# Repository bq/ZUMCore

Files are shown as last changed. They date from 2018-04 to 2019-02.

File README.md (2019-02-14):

# ZUMCore 2
BQ ZUM Core integration on Arduino IDE

This is the evolution of the bqZUM Core board available [here](https://github.com/bq/zum).
Main changes are:
1. Move to Bluetooth Low Energy (BLE).
1. Change from ATMega328P to ATMega328PB.

## Getting Started

### Prerequisites

You need to install latest [Arduino IDE](https://www.arduino.cc/en/Main/Software).

This package has been tested on Arduino IDE 1.8.5.

### Installing

To use the integration with Arduino IDE follow these steps:
1. Open Arduino IDE and go into File -> Preferences.
1. On "Additional Boards Manager URLs:" enter the link to [package_zumcore_1_8_x_index.json](https://raw.githubusercontent.com/bq/ZUMCore/master/package_zumcore_1_8_x_index.json) [right click here and copy link] and press OK.
1. Go to Tools -> Boards -> Board Manager and you will find "ZUM Core for Arduino 1.8.x" ready to be installed. Install latest version.

Now you can choose your Board **BQ ZUM Core**.

You can also find some usefull examples for the board available on the IDE.

### Examples

## Flashing Bootloader

The bootloader can be flashed on ZUM Core using another Arduino board as ISP or any other supported ISP programmer.
For further support check this [link](https://www.arduino.cc/en/Tutorial/ArduinoISP).

## License

This project is licensed under the GPL v3 license.

## Credits

This project relies on Arduino IDE to work.

The project is based on [Elektor UNO R4](https://github.com/ElektorLabs/Arduino/)

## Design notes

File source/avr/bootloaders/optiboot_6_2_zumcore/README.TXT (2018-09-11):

------------------------------------------------------------
bqZUM Core

This is a slightly modified version to make optiboot compile for 
the ATmega16 too. 

The make rules for the Elektor boards are in Makefile.custom.
The easiest way to make this work is to copy this folder and its 
contents to:

  <Arduino>\hardware\arduino\avr\bootloaders\

where <Arduino> is the path to arduino.exe.

Open a command prompt and navigate to the newly added folder, ex:

  <Arduino>\hardware\arduino\avr\bootloaders\optiboot_6_2_zumjunior\

Enter this folder and then try make commands, like this:

  make atmega328pb LED=B5

This should result in a usable HEX file.
------------------------------------------------------------

This directory contains the Optiboot small bootloader for AVR
microcontrollers, somewhat modified specifically for the Arduino
environment.

Optiboot is more fully described here: http://github.com/Optiboot/optiboot
and is the work of Peter Knight (aka Cathedrow), building on work of Jason P
Kyle, Spiff, and Ladyada.  More recent maintenance and modifications are by
Bill Westfield (aka WestfW)

Arduino-specific issues are tracked as part of the Arduino project
at http://github.com/arduino/Arduino

Most of the information in this file is superceeded by the wiki content at
https://github.com/Optiboot/optiboot/wiki

It's till here "just in case."

------------------------------------------------------------

Building optiboot for Arduino.

Production builds of optiboot for Arduino are done on a Mac in "unix mode"
using CrossPack-AVR-20100115.  CrossPack tracks WINAVR (for windows), which
is just a package of avr-gcc and related utilities, so similar builds should
work on Windows or Linux systems.

One of the Arduino-specific changes is modifications to the makefile to
allow building optiboot using only the tools installed as part of the
Arduino environment, or the Arduino source development tree.  All three
build procedures should yield identical binaries (.hex files) (although
this may change if compiler versions drift apart between CrossPack and
the Arduino IDE.)

Building Optiboot in the Arduino IDE Install.

Work in the .../hardware/arduino/bootloaders/optiboot/ and use the
"omake <targets>" command, which just generates a command that uses
the arduino-included "make" utility with a command like:
    make OS=windows ENV=arduino <targets>
or  make OS=macosx ENV=arduino <targets>
On windows, this assumes you're using the windows command shell.  If
you're using a cygwin or mingw shell, or have one of those in your
path, the build will probably break due to slash vs backslash issues.
On a Mac, if you have the developer tools installed, you can use the
Apple-supplied version of make.
The makefile uses relative paths ("../../../tools/" and such) to find
the programs it needs, so you need to work in the existing optiboot
directory (or something created at the same "level") for it to work.

Building Optiboot in the Arduino Source Development Install.

In this case, there is no special shell script, and you're assumed to
have "make" installed somewhere in your path.
Build the Arduino source ("ant build") to unpack the tools into the
expected directory.
Work in Arduino/hardware/arduino/bootloaders/optiboot and use
    make OS=windows ENV=arduinodev <targets>
or  make OS=macosx ENV=arduinodev <targets>

Programming Chips Using the _isp Targets

The CPU targets have corresponding ISP targets that will actuall
program the bootloader into a chip. "atmega328_isp" for the atmega328,
for example.  These will set the fuses and lock bits as appropriate as
well as uploading the bootloader code.

ISP Targets in Version 5.0 and later:

The isp targets are now built using a separate "Makefile.isp" makefile,
which should make modification easier and more obvious.  This also fixes
the atmega8_isp target problem mentioned below.  The default
configuration assumes an ArduinoISP setup, but you will probably need to
update at least the serial port, since those are different for each
Arduino board and/or system/

ISP Targets in Version 4.6 and earlier:

The older makefiles default to using a USB programmer, but you can use a
serial programmer like ArduinoISP by changing the appropriate variables
when you invoke make:

   make ISPTOOL=stk500v1 ISPPORT=/dev/tty.usbserial-A20e1eAN  \
        ISPSPEED=-b19200 atmega328_isp

The "atmega8_isp" target does not currently work, because the mega8
doesn't have the "extended" fuse that the generic ISP target wants to
pass on to avrdude.  You'll need to run avrdude manually.

Standard Targets

I've reduced the pre-built and source-version-controlled targets
(.hex and .lst files included in the git repository) to just the
three basic 16MHz targets: atmega8, atmega16, atmega328.

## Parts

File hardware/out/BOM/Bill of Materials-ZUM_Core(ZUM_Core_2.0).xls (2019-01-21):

 |  |  | BILL OF MATERIALS
PROJECT: |  | ZUM_Core.PrjPcb
TITLE: |  | ZUM Core
VARIANT: |  | ZUM_Core_2.0
DOCUMENT: |  | Bill of Materials
AUTHOR : |  | Andrés Gullón
DATE : |  | 01/06/2018
REV: |  | 1.I.
NOTE | ITEM | Designator | Description | Quantity | Manufacturer | OrderingCode | Supplier | Manufacturer 2 | OrderingCode 2 | Manufacturer 3 | OrderingCode 3 | Manufacturer 4 | OrderingCode 4 | Manufacturer 5 | OrderingCode 5 | Footprint | Value
 | 1 | C1, C2, C7, C8, C10, C17, C20, C21, C22, C26 | C0603_100nF_50V_±10%_X7R | 10 | Kemet | C0603C104K5RAC | - | AVX | 06035C104KAT2A |  |  |  |  |  |  | C0603 | 100nF ±10% 50V
 | 2 | C3, C4, C5, C6, C9, C14 | C0402_2.2uF_16V_±20%_X5R | 6 | TDK | C1005X5R1C225M050BC | - | Taiyo Yuden | EMK105ABJ225MV-F |  |  |  |  |  |  | C0402 | 2,2µF ±20% 16V
 | 3 | C11, C12 | C0402_47pF_16V_±10% | 2 | Kemet | C0402C470K4GAC | - |  |  |  |  |  |  |  |  | C0402 | 47pF ±10% 16V
 | 4 | C13 | C0805_4700pF_250V_±10%_X7R | 1 | Kemet | C0805S472KARACTU | - | Murata | GRM21AR72E472KW01D |  |  |  |  |  |  | C0805 | 4,7nF ±10% 250V
 | 5 | C15 |  | 1 | Kemet | C0603C105K3PAC | - |  |  |  |  |  |  |  |  | C0603 | 1uF ±10% 25V
 | 6 | C16, C27, C28 |  | 3 | Murata | GRM31CR61E226KE15L | - |  |  |  |  |  |  |  |  | C1206 | 22uF ±10% 25V
 | 7 | C18, C23 | C0402_2.2nF_16V_±10% | 2 | Kemet | C0402C222K4RAC | - |  |  |  |  |  |  |  |  | C0402 | 2,2nF ±10% 16V
 | 8 | C19, C32 | C0402_47nF_16V_±10%, [NoValue] | 2 | Kemet | C0402C473K4RAC | - |  |  |  |  |  |  |  |  | C0402 | 47nF ±10% 16V
 | 9 | C24, C25 | C0402_12pF_16V_±10% | 2 | Kemet | C0402C120K4GAC | - |  |  |  |  |  |  |  |  | C0402 | 12pF ±10% 16V
 | 10 | C30 |  | 1 | Vishay | T55B157M6R3C0040 | - |  |  |  |  |  |  |  |  | CASE_B_3528-1411 | 150uF ±20% 6V3
 | 11 | C31 |  | 1 | Panasonic | EEE-HA1E101XP | - |  |  |  |  |  |  |  |  | CASE_D_7.7 | 100uF 25V
 | 12 | C33 |  | 1 | Kemet | C0402C104K9RAC | - |  |  |  |  |  |  |  |  | C0402 | 100nF ±10% 6V3
 | 13 | D1 | Schottky Diode | 1 | NXP | BAT54S | - | Vishay | BAT54S |  |  |  |  |  |  | SOT23-3 | 200mA 30V
 | 14 | D2, D6 | Schottky Diode | 2 | NXP | PMEG3030EP | - |  |  |  |  |  |  |  |  | SOD128 | 3A 30V
 | 15 | D3, D4, TX | LED | 3 | Avago Technologies | HSMG-C190 | - | OSRAM Opto | LG Q971-KN-1 |  |  |  |  |  |  | LED0603 | Green
 | 16 | F1 | Resettable Fuses | 1 | Bel Fuse | 0ZCG0260BF2B | - | Littelfuse | MINISMDC260F/16-2 | Bourns | MF-MSMF250/16X-2 |  |  |  |  | F1812
 | 17 | F2 | TVS Diode Array | 1 | Würth Elektronik | 82400152 | - | Bourns | CDSOT563-0502 |  |  |  |  |  |  | SOT563
 | 18 | F3 | Resettable Fuses | 1 | Bourns | MF-MSMF050-2 | - |  |  |  |  |  |  |  |  | F1812
 | 19 | F4 | 2.45GHz Impedance Matched Balun + Band Pass Filter | 1 | Johanson | 2450BM14E0003 | - |  |  |  |  |  |  |  |  | BAL-0603-6PIN | Balun 2.45GHz
 | 20 | J1 | Micro USB Type B W/ Rear Pegs | 1 | FCI | 10118194-0001LF | - |  |  |  |  |  |  |  |  | USB_B_W_REAR_PEGS
 | 21 | J2 | Connector | 1 | Samtec | TSW-108-07-T-S-NATURAL | - |  |  |  |  |  |  |  |  | 1x8 Pin Header 2.54
 | 22 | J3 | Connector | 1 | Samtec | TSW-108-07-T-S-RED | - |  |  |  |  |  |  |  |  | 1x8 Pin Header 2.54
 | 23 | J4 | Connector | 1 | Samtec | TSW-108-07-T-S | - | Würth Elektronik | 613 008 111 21 |  |  |  |  |  |  | 1x8 Pin Header 2.54 | 8
 | 24 | J5, J11 | Connector | 2 | Samtec | SSW-108-01-T-S | - | Würth Elektronik | 613 008 118 21 |  |  |  |  |  |  | 1x8 Socket Header THT 2.54mm | 8
 | 25 | J6 | Connector | 1 | Samtec | TSW-106-07-T-S-NATURAL | - |  |  |  |  |  |  |  |  | 1x8 Header 2.54 (3D Mod)
 | 26 | J7, J13 | Connector | 2 | Samtec | TSW-106-07-T-S-RED | - |  |  |  |  |  |  |  |  | 1x8 Header 2.54 (3D Mod), 1x6 Pin Header 2.54
 | 27 | J8, J14 | Connector | 2 | Samtec | TSW-106-07-T-S | - | Würth Elektronik | 613 006 111 21 |  |  |  |  |  |  | 1x8 Header 2.54 (3D Mod), 1x6 Pin Header 2.54 | 6
 | 28 | J9 | Connector | 1 | Samtec | SSW-106-01-T-S | - | Würth Elektronik | 613 006 118 21 |  |  |  |  |  |  | 1x6 Socket Header THT 2.54mm | 6
 | 29 | J10 | Connector | 1 | Samtec | TSW-103-07-T-D | - | Würth Elektronik | 613 006 211 21 |  |  |  |  |  |  | 2x3 Pin Header 2.54 | 6
 | 30 | J12 | Connector | 1 | Samtec | TSW-106-07-T-S-BLUE | - |  |  |  |  |  |  |  |  | 1x6 Pin Header 2.54
 | 31 | J15 | Connector | 1 | Samtec | SSW-110-01-T-S | - | Würth Elektronik | 613 010 118 21 |  |  |  |  |  |  | 1x10 Socket Header THT 2.54mm | 10
 | 32 | J_PWR | Connector | 1 | Kycon | KLDHCX0202A | - | Switchcraft | RAPC722X |  |  |  |  |  |  | Jack 2.1
 | 33 | L1 | L0603_120R_0,025R_3000mA | 1 | Murata | BLM18SG121TN1D | - |  |  |  |  |  |  |  |  | L0603 | 120R 0,025R 3000mA
 | 34 | L2 |  | 1 | Würth Elektronik | 742792012 | - |  |  |  |  |  |  |  |  | L0805 | 33R 0,008R 4000mA
 | 35 | L3 | Semi-shielded power inductor | 1 | Bourns | SRN8040-2R2Y | - |  |  |  |  |  |  |  |  | SRN8040 | 2,2µH 6,3A
 | 36 | LD4 | LED | 1 | Lite-On | LTST-C194TBKT | - | Avago Technologies | HSMN-C120 |  |  |  |  |  |  | LED0603 | Blue
 | 37 | Q1, Q2, Q3, Q4 | P-MOSFET transistor | 4 | Diodes Incorporated | DMP2035U-7 | - |  |  |  |  |  |  |  |  | SOT23-3
 | 38 | R1, R7 | R0603_1M_0.1W_±5% | 2 | Vishay | CRCW06031M00JN | - |  |  |  |  |  |  |  |  | R0603 | 1M ±5% 0.1W
 | 39 | R2, R4, R5, R15 | R0402_1k_0.063W_±5% | 4 | Vishay | CRCW04021K00JN | - |  |  |  |  |  |  |  |  | R0402 | 1k ±5% 0.063W
 | 40 | R3 | R0402_10R_0.063W_±1% | 1 | Vishay | CRCW040210R0FK | - | Yageo | RC0402FR-0710RL |  |  |  |  |  |  | R0402 | '=Resistance+' '+Tolerance+' '+Power
 | 41 | R6, R11, R19 | R0402_100k_0.063W_±1%, [NoValue], [NoValue] | 3 | Vishay | CRCW0402100KFK | - |  |  |  |  |  |  |  |  | R0402 | 100k ±1% 0.063W
 | 42 | R8, R18, R20, R23 | R0402_330R_0.063W_±5% | 4 | Vishay | CRCW0402330RJN | - |  |  |  |  |  |  |  |  | R0402 | 330R ±5% 0.063W
 | 43 | R9, R14, R22 |  | 3 | Vishay | CRCW040252K3FK | - |  |  |  |  |  |  |  |  | R0402 | 52,3k ±1% 0.063W
 | 44 | R10, R17, R25 | R0402_10k_0.063W_±5% | 3 | Vishay | CRCW040210K0JN | - | Yageo | RC0402JR-0710KL |  |  |  |  |  |  | R0402 | 10k ±5% 0.063W
 | 45 | R12 | R0402_20R_0.063W_±5% | 1 | Vishay | CRCW040220R0JN | - |  |  |  |  |  |  |  |  | R0402 | 20R ±5% 0.063W
 | 46 | R13 | R0402_75k_0.063W_±1% | 1 | Vishay | CRCW040275K0FK | - | Yageo | RC0402FR-0775KL |  |  |  |  |  |  | R0402 | 75k ±1% 0.063W
 | 47 | R16 | R0402_82k_0.063W_±1% | 1 | Vishay | CRCW040282K0FK | - | Yageo | RC0402FR-0782KL |  |  |  |  |  |  | R0402 | 82k ±1% 0.063W
 | 48 | R24 | R0402_30k_0.063W_±1% | 1 | Vishay | CRCW040230K0FK | - |  |  |  |  |  |  |  |  | R0402 | 30k ±1% 0.063W
 | 49 | RX | LED | 1 | Avago Technologies | HSMH-C190 | - | OSRAM Opto | LS Q976-NR-1 |  |  |  |  |  |  | LED0603 | Red
 | 50 | SW1 | Switch | 1 | C&K Components | PTS645VL39-2 LFS | - |  |  |  |  |  |  |  |  | SW_Vert_THT_7.5x6x6.5
 | 51 | SW2 | Switch | 1 | Würth Elektronik | 450 302 014 072 | - | Knitter-Switch | MMP1010D-RA |  |  |  |  |  |  | Slide SW SPDT Right Angle
 | 52 | U1 | 8-bit Microcontrollers - MCU 32KB In-system Flash 20MHz 1.8V-5.5V | 1 | Atmel | ATMEGA328PB-AU | - |  |  |  |  |  |  |  |  | TQFP32
 | 53 | U2 | USB to UART Bridge | 1 | Silicon Labs | CP2104-F03-GMR | - |  |  |  |  |  |  |  |  | QFN24_no_power
 | 54 | U3 | DCDC Step Down Vout= 1-5V; Vin= 12-17V | 1 | MPS | MP1477GTF-Z | - |  |  |  |  |  |  |  |  | SOT-563 - MP1477H
 | 55 | U4 | Multiplexer | 1 | Texas Instruments | SN74CBT3257CPWR | - |  |  |  |  |  |  |  |  | TSSOP16
 | 56 | U5 | Multiprotocol Bluetooth® low energy/2.4 GHz RF System on Chip | 1 | Nordic | NRF51822-QFAB-T | - |  |  |  |  |  |  |  |  | QFN_48_6x6mm | BLE
 | 57 | U6 | LDO Vin: 3-40V Vout: 1.2-15V @300mA | 1 | Monolithic Power Systems | MP2019GN-Z | - |  |  |  |  |  |  |  |  | SOIC8 EP
 | 58 | Y1 | Resonator 16MHz | 1 | Murata | CSTCE16M0V53-R0 | - |  |  |  |  |  |  |  |  | Resonator_1.3x3.2 | 16MHz
 | 59 | Y2 | Crystal 16 MHz | 1 | Abracon | ABM8G-16.000MHZ-B4Y-T | - | TXC | 7V-16.000MAHQ-T | CTS | 403C35A16M00000 |  |  |  |  | ABM8G_3.2x2.5mm | 16MHz
 | 60 | Zs | R0402_0R_0.063W_±5% | 1 | Panasonic | ERJ-2GE0R00X | - | Yageo | RC0402FR-070RL | Vishay | CRCW04020000Z0 |  |  |  |  | R0402 | 0R ±5% 0.063W
NOTES:

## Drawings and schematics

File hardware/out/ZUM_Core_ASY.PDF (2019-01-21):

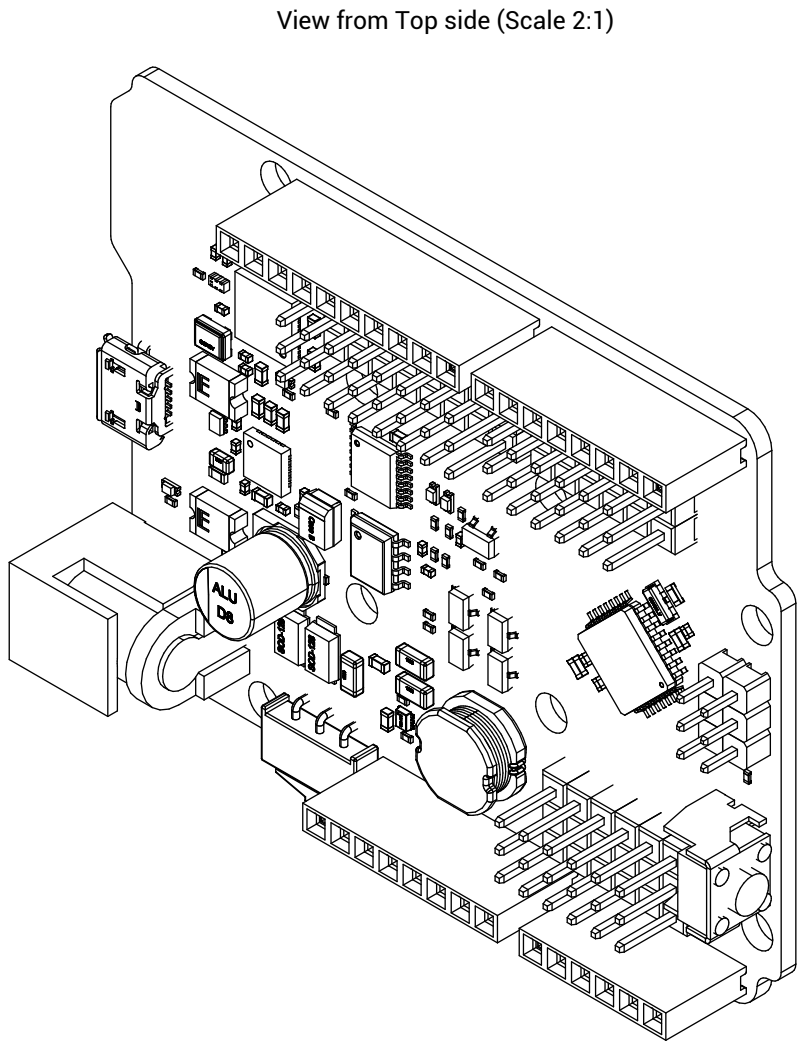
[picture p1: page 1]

View from Top side (Scale 2:1)

ZUM_Core_2.0 | SCALE | 2:1

REVISION | =1.I.1
UNIT | UNLESS OTHERWISE SPECIFIED: DIMENSIONS ARE IN MILLIMETERS

PROJECTION

A3 | SHEET 1 OF 2

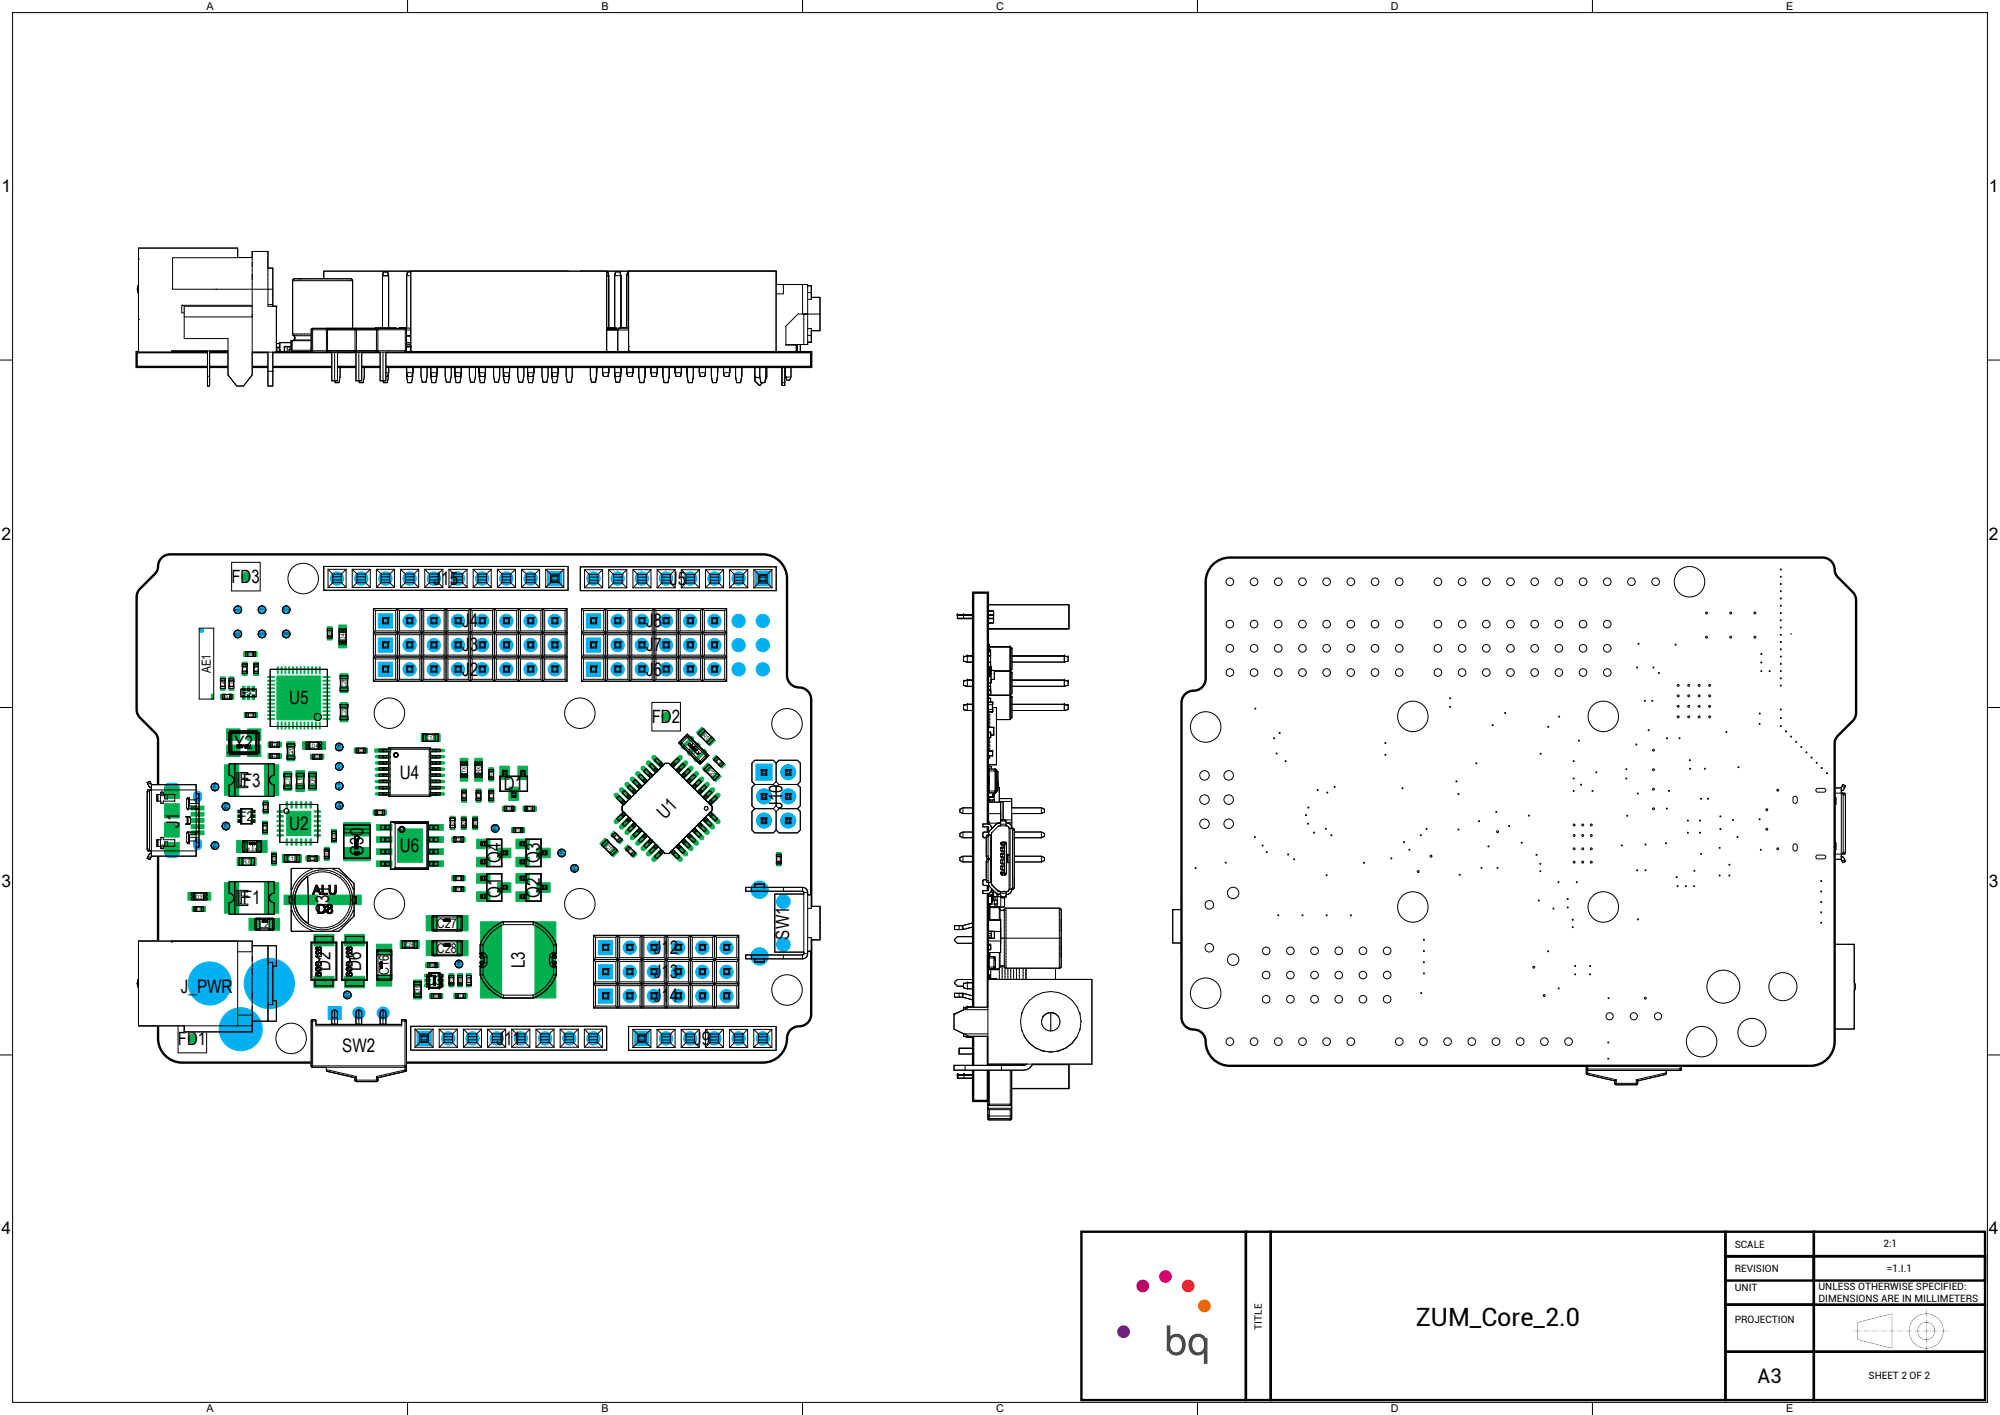
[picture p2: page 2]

ZUM_Core_2.0 | SCALE | 2:1

REVISION | =1.I.1
UNIT | UNLESS OTHERWISE SPECIFIED: DIMENSIONS ARE IN MILLIMETERS

PROJECTION

A3 | SHEET 2 OF 2

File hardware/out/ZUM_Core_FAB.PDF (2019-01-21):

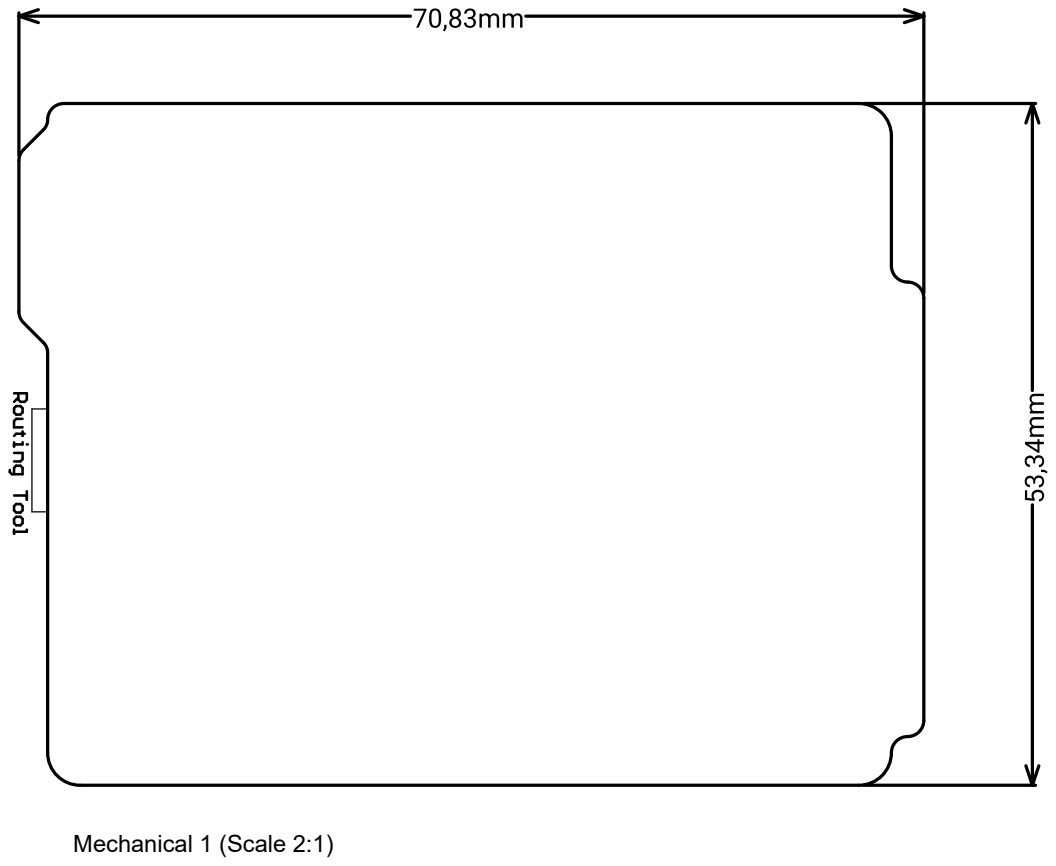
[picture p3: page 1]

SURFACE FINISH: | | SOLDERMASK COLOR: TITLE ZUM_Core_2.0 | SCALE | 2:1

HAL / Inmersion TIN / Inmersion Silver | White | SILKSCREEN COLOR: Black

REVISION | =1.I.1
UNIT | UNLESS OTHERWISE SPECIFIED: DIMENSIONS ARE IN MILLIMETERS

PROJECTION

A3 | SHEET 1 OF 3

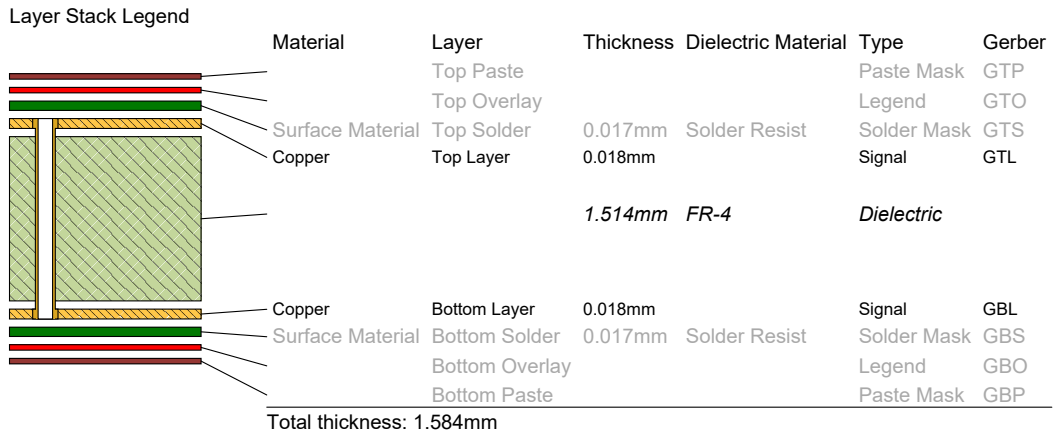
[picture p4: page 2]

SURFACE FINISH: | | SOLDERMASK COLOR: TITLE | SCALE | 2:1

HAL / Inmersion TIN / Inmersion Silver | White | SILKSCREEN COLOR: Black

REVISION | =1.I.1
UNIT | UNLESS OTHERWISE SPECIFIED:

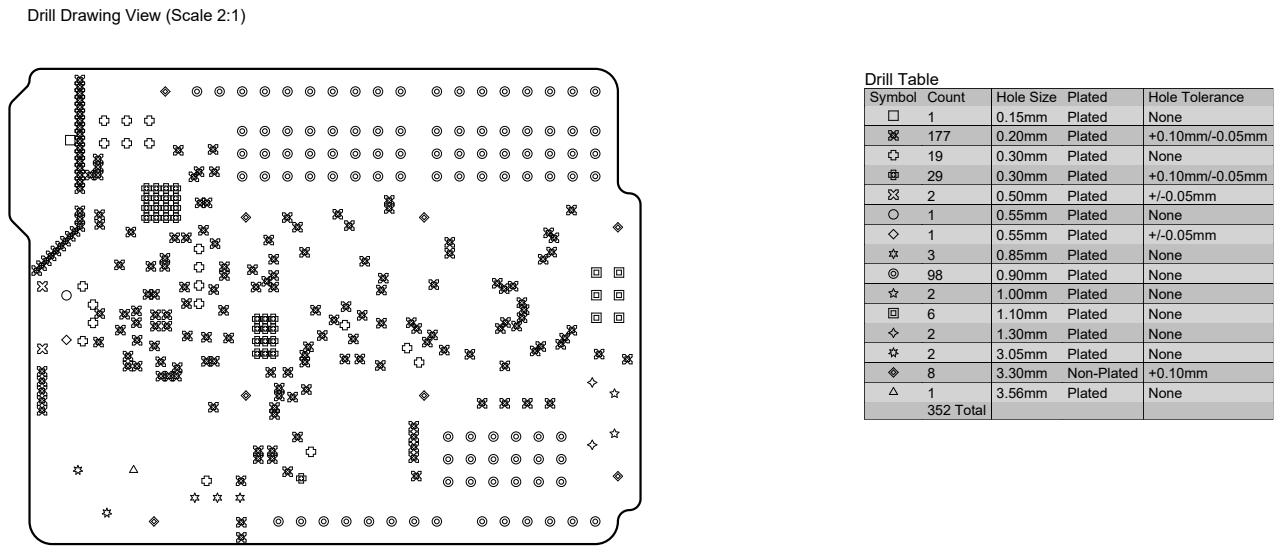
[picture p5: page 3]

Drill Drawing View (Scale 2:1)

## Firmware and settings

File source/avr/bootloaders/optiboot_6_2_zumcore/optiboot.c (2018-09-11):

#define FUNC_READ 1
#define FUNC_WRITE 1
/**********************************************************/
/* Optiboot bootloader for Arduino                        */
/*                                                        */
/* http://optiboot.googlecode.com                         */
/*                                                        */
/* Arduino-maintained version : See README.TXT            */
/* http://code.google.com/p/arduino/                      */
/*  It is the intent that changes not relevant to the     */
/*  Arduino production envionment get moved from the      */
/*  optiboot project to the arduino project in "lumps."   */
/*                                                        */
/* Heavily optimised bootloader that is faster and        */
/* smaller than the Arduino standard bootloader           */
/*                                                        */
/* Enhancements:                                          */
/*   Fits in 512 bytes, saving 1.5K of code space         */
/*   Higher baud rate speeds up programming               */
/*   Written almost entirely in C                         */
/*   Customisable timeout with accurate timeconstant      */
/*   Optional virtual UART. No hardware UART required.    */
/*   Optional virtual boot partition for devices without. */
/*                                                        */
/* What you lose:                                         */
/*   Implements a skeleton STK500 protocol which is       */
/*     missing several features including EEPROM          */
/*     programming and non-page-aligned writes            */
/*   High baud rate breaks compatibility with standard    */
/*     Arduino flash settings                             */
/*                                                        */
/* Fully supported:                                       */
/*   ATmega168 based devices  (Diecimila etc)             */
/*   ATmega328P based devices (Duemilanove etc)           */
/*                                                        */
/* Beta test (believed working.)                          */
/*   ATmega8 based devices (Arduino legacy)               */
/*   ATmega328 non-picopower devices                      */
/*   ATmega644P based devices (Sanguino)                  */
/*   ATmega1284P based devices                            */
/*   ATmega1280 based devices (Arduino Mega)              */
/*                                                        */
/* Alpha test                                             */
/*   ATmega32                                             */
/*                                                        */
/* Work in progress:                                      */
/*   ATtiny84 based devices (Luminet)                     */
/*                                                        */
/* Does not support:                                      */
/*   USB based devices (eg. Teensy, Leonardo)             */
/*                                                        */
/* Assumptions:                                           */
/*   The code makes several assumptions that reduce the   */
/*   code size. They are all true after a hardware reset, */
/*   but may not be true if the bootloader is called by   */
/*   other means or on other hardware.                    */
/*     No interrupts can occur                            */
/*     UART and Timer 1 are set to their reset state      */
/*     SP points to RAMEND                                */
/*                                                        */
/* Code builds on code, libraries and optimisations from: */
/*   stk500boot.c          by Jason P. Kyle               */
/*   Arduino bootloader    http://arduino.cc              */
/*   Spiff's 1K bootloader http://spiffie.org/know/arduino_1k_bootloader/bootloader.shtml */
/*   avr-libc project      http://nongnu.org/avr-libc     */
/*   Adaboot               http://www.ladyada.net/library/arduino/bootloader.html */
/*   AVR305                Atmel Application Note         */
/*                                                        */

/* Copyright 2013-2015 by Bill Westfield.                 */
/* Copyright 2010 by Peter Knight.                        */
/*                                                        */
/* This program is free software; you can redistribute it */
/* and/or modify it under the terms of the GNU General    */
/* Public License as published by the Free Software       */
/* Foundation; either version 2 of the License, or        */
/* (at your option) any later version.                    */
/*                                                        */
/* This program is distributed in the hope that it will   */
/* be useful, but WITHOUT ANY WARRANTY; without even the  */
/* implied warranty of MERCHANTABILITY or FITNESS FOR A   */
/* PARTICULAR PURPOSE.  See the GNU General Public        */
/* License for more details.                              */
/*                                                        */
/* You should have received a copy of the GNU General     */
/* Public License along with this program; if not, write  */
/* to the Free Software Foundation, Inc.,                 */
/* 59 Temple Place, Suite 330, Boston, MA  02111-1307 USA */
/*                                                        */
/* Licence can be viewed at                               */
/* http://www.fsf.org/licenses/gpl.txt                    */
/*                                                        */
/**********************************************************/


/**********************************************************/
/*                                                        */
/* Optional defines:                                      */
/*                                                        */
/**********************************************************/
/*                                                        */
/* BIGBOOT:                                              */
/* Build a 1k bootloader, not 512 bytes. This turns on    */
/* extra functionality.                                   */
/*                                                        */
/* BAUD_RATE:                                             */
/* Set bootloader baud rate.                              */
/*                                                        */
/* SOFT_UART:                                             */
/* Use AVR305 soft-UART instead of hardware UART.         */
/*                                                        */
/* LED_START_FLASHES:                                     */
/* Number of LED flashes on bootup.                       */
/*                                                        */
/* LED_DATA_FLASH:                                        */
/* Flash LED when transferring data. For boards without   */
/* TX or RX LEDs, or for people who like blinky lights.   */
/*                                                        */
/* SUPPORT_EEPROM:                                        */
/* Support reading and writing from EEPROM. This is not   */
/* used by Arduino, so off by default.                    */
/*                                                        */
/* TIMEOUT_MS:                                            */
/* Bootloader timeout period, in milliseconds.            */
/* 500,1000,2000,4000,8000 supported.                     */
/*                                                        */
/* UART:                                                  */
/* UART number (0..n) for devices with more than          */
/* one hardware uart (644P, 1284P, etc)                   */
/*                                                        */
/**********************************************************/


/**********************************************************/
/* Version Numbers!                                       */
/*                                                        */
/* Arduino Optiboot now includes this Version number in   */
/* the source and object code.                            */
/*                                                        */
/* Version 3 was released as zip from the optiboot        */
/*  repository and was distributed with Arduino 0022.     */
/* Version 4 starts with the arduino repository commit    */
/*  that brought the arduino repository up-to-date with   */
/*  the optiboot source tree changes since v3.            */
/* Version 5 was created at the time of the new Makefile  */
/*  structure (Mar, 2013), even though no binaries changed*/
/* It would be good if versions implemented outside the   */
/*  official repository used an out-of-seqeunce version   */
/*  number (like 104.6 if based on based on 4.5) to       */
/*  prevent collisions.                                   */
/*                                                        */
/**********************************************************/

/**********************************************************/
/* Edit History:					  */
/*							  */
/* Aug 2014						  */
/* 6.2 WestfW: make size of length variables dependent    */
/*              on the SPM_PAGESIZE.  This saves space    */
/*              on the chips where it's most important.   */
/* 6.1 WestfW: Fix OPTIBOOT_CUSTOMVER (send it!)	  */
/*             Make no-wait mod less picky about	  */
/*               skipping the bootloader.		  */
/*             Remove some dead code			  */
/* Jun 2014						  */
/* 6.0 WestfW: Modularize memory read/write functions	  */
/*             Remove serial/flash overlap		  */
/*              (and all references to NRWWSTART/etc)	  */
/*             Correctly handle pagesize > 255bytes       */
/*             Add EEPROM support in BIGBOOT (1284)       */
/*             EEPROM write on small chips now causes err */
/*             Split Makefile into smaller pieces         */
/*             Add Wicked devices Wildfire		  */
/*	       Move UART=n conditionals into pin_defs.h   */
/*	       Remove LUDICOUS_SPEED option		  */
/*	       Replace inline assembler for .version      */
/*              and add OPTIBOOT_CUSTOMVER for user code  */
/*             Fix LED value for Bobuino (Makefile)       */
/*             Make all functions explicitly inline or    */
/*              noinline, so we fit when using gcc4.8     */
/*             Change optimization options for gcc4.8	  */
/*             Make ENV=arduino work in 1.5.x trees.	  */
/* May 2014                                               */
/* 5.0 WestfW: Add support for 1Mbps UART                 */
/* Mar 2013                                               */
/* 5.0 WestfW: Major Makefile restructuring.              */
/*             See Makefile and pin_defs.h                */
/*             (no binary changes)                        */
/*                                                        */
/* 4.6 WestfW/Pito: Add ATmega32 support                  */
/* 4.6 WestfW/radoni: Don't set LED_PIN as an output if   */
/*                    not used. (LED_START_FLASHES = 0)   */
/* Jan 2013						  */
/* 4.6 WestfW/dkinzer: use autoincrement lpm for read     */
/* 4.6 WestfW/dkinzer: pass reset cause to app in R2      */
/* Mar 2012                                               */
/* 4.5 WestfW: add infrastructure for non-zero UARTS.     */
/* 4.5 WestfW: fix SIGNATURE_2 for m644 (bad in avr-libc) */
/* Jan 2012:                                              */
/* 4.5 WestfW: fix NRWW value for m1284.                  */
/* 4.4 WestfW: use attribute OS_main instead of naked for */
/*             main().  This allows optimizations that we */
/*             count on, which are prohibited in naked    */
/*             functions due to PR42240.  (keeps us less  */
/*             than 512 bytes when compiler is gcc4.5     */
/*             (code from 4.3.2 remains the same.)        */
/* 4.4 WestfW and Maniacbug:  Add m1284 support.  This    */
/*             does not change the 328 binary, so the     */
/*             version number didn't change either. (?)   */
/* June 2011:                                             */
/* 4.4 WestfW: remove automatic soft_uart detect (didn't  */
/*             know what it was doing or why.)  Added a   */
/*             check of the calculated BRG value instead. */
/*             Version stays 4.4; existing binaries are   */
/*             not changed.                               */
/* 4.4 WestfW: add initialization of address to keep      */
/*             the compiler happy.  Change SC'ed targets. */
/*             Return the SW version via READ PARAM       */
/* 4.3 WestfW: catch framing errors in getch(), so that   */
/*             AVRISP works without HW kludges.           */
/*  http://code.google.com/p/arduino/issues/detail?id=368n*/
/* 4.2 WestfW: reduce code size, fix timeouts, change     */
/*             verifySpace to use WDT instead of appstart */
/* 4.1 WestfW: put version number in binary.		  */
/**********************************************************/

#define OPTIBOOT_MAJVER 6
#define OPTIBOOT_MINVER 2

/*
 * OPTIBOOT_CUSTOMVER should be defined (by the makefile) for custom edits
 * of optiboot.  That way you don't wind up with very different code that
 * matches the version number of a "released" optiboot.
 */

#if !defined(OPTIBOOT_CUSTOMVER)
#define OPTIBOOT_CUSTOMVER 0
#endif

unsigned const int __attribute__((section(".version"))) 
optiboot_version = 256*(OPTIBOOT_MAJVER + OPTIBOOT_CUSTOMVER) + OPTIBOOT_MINVER;



#include <inttypes.h>
#include <avr/io.h>
#include <avr/pgmspace.h>
#include <avr/eeprom.h>

/*
 * Note that we use our own version of "boot.h"
 * <avr/boot.h> uses sts instructions, but this version uses out instructions
 * This saves cycles and program memory.  Sorry for the name overlap.
 */
#include "boot.h"


// We don't use <avr/wdt.h> as those routines have interrupt overhead we don't need.

/*
 * pin_defs.h
 * This contains most of the rather ugly defines that implement our
 * ability to use UART=n and LED=D3, and some avr family bit name differences.
 */
#include "pin_defs.h"

/*
 * stk500.h contains the constant definitions for the stk500v1 comm protocol
 */
#include "stk500.h"
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
int main(void) {
  uint8_t ch;

  /*
   * Making these local and in registers prevents the need for initializing
   * them, and also saves space because code no longer stores to memory.
   * (initializing address keeps the compiler happy, but isn't really
   *  necessary, and uses 4 bytes of flash.)
   */
  register uint16_t address = 0;
  register pagelen_t  length;

  // After the zero init loop, this is the first code to run.
  //
  // This code makes the following assumptions:
  //  No interrupts will execute
  //  SP points to RAMEND
  //  r1 contains zero
  //
  // If not, uncomment the following instructions:
  // cli();
  asm volatile ("clr __zero_reg__");
#if defined(__AVR_ATmega8__) || defined (__AVR_ATmega32__) || defined (__AVR_ATmega16__) // CPV: added ATmega16.
  SP=RAMEND;  // This is done by hardware reset
#endif

  /*
   * modified Adaboot no-wait mod.
   * Pass the reset reason to app.  Also, it appears that an Uno poweron
   * can leave multiple reset flags set; we only want the bootloader to
   * run on an 'external reset only' status
   */
  ch = MCUSR;
  MCUSR = 0;
  if (ch & (_BV(WDRF) | _BV(BORF) | _BV(PORF)))
      appStart(ch);

#if LED_START_FLASHES > 0
  // Set up Timer 1 for timeout counter
  TCCR1B = _BV(CS12) | _BV(CS10); // div 1024
#endif

#ifndef SOFT_UART
#if defined(__AVR_ATmega8__) || defined (__AVR_ATmega32__) || defined (__AVR_ATmega16__) // CPV: added ATmega16.
  UCSRA = _BV(U2X); //Double speed mode USART
  UCSRB = _BV(RXEN) | _BV(TXEN);  // enable Rx & Tx
  UCSRC = _BV(URSEL) | _BV(UCSZ1) | _BV(UCSZ0);  // config USART; 8N1
  UBRRL = (uint8_t)( (F_CPU + BAUD_RATE * 4L) / (BAUD_RATE * 8L) - 1 );
#else
  UART_SRA = _BV(U2X0); //Double speed mode USART0
  UART_SRB = _BV(RXEN0) | _BV(TXEN0);
  UART_SRC = _BV(UCSZ00) | _BV(UCSZ01);
  UART_SRL = (uint8_t)( (F_CPU + BAUD_RATE * 4L) / (BAUD_RATE * 8L) - 1 );
#endif
#endif

  // Set up watchdog to trigger after 1s
  watchdogConfig(WATCHDOG_1S);

#if (LED_START_FLASHES > 0) || defined(LED_DATA_FLASH)
  /* Set LED pin as output */
  LED_DDR |= _BV(LED);
#endif

#ifdef SOFT_UART
  /* Set TX pin as output */
  UART_DDR |= _BV(UART_TX_BIT);
#endif

#if LED_START_FLASHES > 0
  /* Flash onboard LED to signal entering of bootloader */
  flash_led(LED_START_FLASHES * 2);
#endif

//  putch(0x56); // Commented line to avoid 'V' UART transmission 

  /* Forever loop: exits by causing WDT reset */
  for (;;) {
    /* get character from UART */
    ch = getch();

    if(ch == STK_GET_PARAMETER) {
      unsigned char which = getch();
      verifySpace();
      /*
       * Send optiboot version as "SW version"
       * Note that the references to memory are optimized away.
       */
      if (which == 0x82) {
	  putch(optiboot_version & 0xFF);
      } else if (which == 0x81) {
	  putch(optiboot_version >> 8);
      } else {
	/*
	 * GET PARAMETER returns a generic 0x03 reply for
         * other parameters - enough to keep Avrdude happy
	 */
	putch(0x03);
      }
    }
    else if(ch == STK_SET_DEVICE) {
      // SET DEVICE is ignored
      getNch(20);
    }
    else if(ch == STK_SET_DEVICE_EXT) {
      // SET DEVICE EXT is ignored
      getNch(5);
    }
    else if(ch == STK_LOAD_ADDRESS) {
      // LOAD ADDRESS
      uint16_t newAddress;
      newAddress = getch();
      newAddress = (newAddress & 0xff) | (getch() << 8);
#ifdef RAMPZ
      // Transfer top bit to RAMPZ
      RAMPZ = (newAddress & 0x8000) ? 1 : 0;
#endif
      newAddress += newAddress; // Convert from word address to byte address
      address = newAddress;
      verifySpace();
    }
    else if(ch == STK_UNIVERSAL) {
      // UNIVERSAL command is ignored
      getNch(4);
      putch(0x00);
    }
    /* Write memory, length is big endian and is in bytes */
    else if(ch == STK_PROG_PAGE) {
      // PROGRAM PAGE - we support flash programming only, not EEPROM
      uint8_t desttype;
      uint8_t *bufPtr;
      pagelen_t savelength;

      GETLENGTH(length);
      savelength = length;
      desttype = getch();

      // read a page worth of contents
      bufPtr = buff;
      do *bufPtr++ = getch();
      while (--length);

      // Read command terminator, start reply
      verifySpace();

#ifdef VIRTUAL_BOOT_PARTITION
#if FLASHEND > 8192
/*
 * AVR with 4-byte ISR Vectors and "jmp"
 * WARNING: this works only up to 128KB flash!
 */
      if (address == 0) {
	// This is the reset vector page. We need to live-patch the
	// code so the bootloader runs first.
	//
	// Save jmp targets (for "Verify")
	rstVect0_sav = buff[rstVect0];
	rstVect1_sav = buff[rstVect1];
	saveVect0_sav = buff[saveVect0];
	saveVect1_sav = buff[saveVect1];

        // Move RESET jmp target to 'save' vector
        buff[saveVect0] = rstVect0_sav;
        buff[saveVect1] = rstVect1_sav;

        // Add jump to bootloader at RESET vector
        // WARNING: this works as long as 'main' is in first section
        buff[rstVect0] = ((uint16_t)main) & 0xFF;
        buff[rstVect1] = ((uint16_t)main) >> 8;
      }

#else
/*
 * AVR with 2-byte ISR Vectors and rjmp
 */
      if ((uint16_t)(void*)address == rstVect0) {
        // This is the reset vector page. We need to live-patch
        // the code so the bootloader runs first.
        //
        // Move RESET vector to 'save' vector
	// Save jmp targets (for "Verify")
	rstVect0_sav = buff[rstVect0];
	rstVect1_sav = buff[rstVect1];
	saveVect0_sav = buff[saveVect0];
	saveVect1_sav = buff[saveVect1];

	// Instruction is a relative jump (rjmp), so recalculate.
	uint16_t vect=(rstVect0_sav & 0xff) | ((rstVect1_sav & 0x0f)<<8); //calculate 12b displacement
	vect = (vect-save_vect_num) & 0x0fff; //substract 'save' interrupt position and wrap around 4096
        // Move RESET jmp target to 'save' vector
        buff[saveVect0] = vect & 0xff;
        buff[saveVect1] = (vect >> 8) | 0xc0; //
        // Add rjump to bootloader at RESET vector
        vect = ((uint16_t)main) &0x0fff; //WARNIG: this works as long as 'main' is in first section
        buff[0] = vect & 0xFF; // rjmp 0x1c00 instruction
	buff[1] = (vect >> 8) | 0xC0;
      }
#endif // FLASHEND
#endif // VBP

      writebuffer(desttype, buff, address, savelength);


    }
    /* Read memory block mode, length is big endian.  */
    else if(ch == STK_READ_PAGE) {
      uint8_t desttype;
      GETLENGTH(length);

      desttype = getch();

      verifySpace();

      read_mem(desttype, address, length);
    }

    /* Get device signature bytes  */
    else if(ch == STK_READ_SIGN) {
      // READ SIGN - return what Avrdude wants to hear
      verifySpace();
      putch(SIGNATURE_0);
      putch(SIGNATURE_1);
      putch(SIGNATURE_2);
    }
    else if (ch == STK_LEAVE_PROGMODE) { /* 'Q' */
      // Adaboot no-wait mod
      watchdogConfig(WATCHDOG_16MS);
      verifySpace();
    }
    else {
      // This covers the response to commands like STK_ENTER_PROGMODE
      verifySpace();
    }
    putch(STK_OK);
  }
}

void putch(char ch) {
#ifndef SOFT_UART
  while (!(UART_SRA & _BV(UDRE0)));
  UART_UDR = ch;
#else
  __asm__ __volatile__ (
    "   com %[ch]\n" // ones complement, carry set
    "   sec\n"
    "1: brcc 2f\n"
    "   cbi %[uartPort],%[uartBit]\n"
    "   rjmp 3f\n"
    "2: sbi %[uartPort],%[uartBit]\n"
    "   nop\n"
    "3: rcall uartDelay\n"
    "   rcall uartDelay\n"
    "   lsr %[ch]\n"
    "   dec %[bitcnt]\n"
    "   brne 1b\n"
    :
    :
      [bitcnt] "d" (10),
      [ch] "r" (ch),
      [uartPort] "I" (_SFR_IO_ADDR(UART_PORT)),
      [uartBit] "I" (UART_TX_BIT)
    :
      "r25"
  );
#endif
}

uint8_t getch(void) {
  uint8_t ch;

#ifdef LED_DATA_FLASH
#if defined(__AVR_ATmega8__) || defined (__AVR_ATmega32__) || defined (__AVR_ATmega16__) // CPV: added ATmega16.
  LED_PORT ^= _BV(LED);
#else
  LED_PIN |= _BV(LED);
#endif
#endif
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

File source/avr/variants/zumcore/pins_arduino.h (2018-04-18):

/*
  pins_arduino.h - Pin definition functions for Arduino
  Part of Arduino - http://www.arduino.cc/

  Copyright (c) 2007 David A. Mellis

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
  $Id: wiring.h 249 2007-02-03 16:52:51Z mellis $
*/

#ifndef Pins_Arduino_h
#define Pins_Arduino_h

#include <avr/pgmspace.h>

#include "avr/iom328p.h"

#undef LED_BUILTIN
#define LED_BUILTIN  (13)

// Pin  0 -  7: PD0-7
// Pin  8 - 13: PB0-5
// Pin 14 - 19: PC0-5
// Pin 20 - 21: PE2-3
// Pin 22 - 23: PE0-1

#define NUM_DIGITAL_PINS  (24) // ZUM Junior has 24 instead of 20 GPIOs.
#define NUM_ANALOG_INPUTS   (8) // ZUM Junior has 8 instead of 6 analog inputs.

#define analogInputToDigitalPin(p)  (((p)<8)? (p)+14 : -1)

#define digitalPinHasPWM(p)  ((p)<=3) || (p)==5 || (p)==6 || (p)==9 || (p)==10 || (p)==11)

// SPI, SPI is also SPI0
static const uint8_t SS   = 10; // PB2
static const uint8_t MOSI = 11; // PB3
static const uint8_t MISO = 12; // PB4
static const uint8_t SCK  = 13; // PB5
// SPI0
static const uint8_t SS0   = 10; // PB2
static const uint8_t MOSI0 = 11; // PB3
static const uint8_t MISO0 = 12; // PB4
static const uint8_t SCK0  = 13; // PB5
// SPI1
static const uint8_t SS1   = 20; // PE2
static const uint8_t MOSI1 = 21; // PE3
static const uint8_t MISO1 = 14; // PC0
static const uint8_t SCK1  = 15; // PC1

// I2C / TWI, SDA/SCL is also SDA0/SCL0
static const uint8_t SDA = 18; // PC4
static const uint8_t SCL = 19; // PC5
// I2C0
static const uint8_t SDA0 = 18; // PC4
static const uint8_t SCL0 = 19; // PC5
// I2C1
static const uint8_t SDA1 = 22; // PE0
static const uint8_t SCL1 = 23; // PE1

// Analog inputs
static const uint8_t A0 = 14; // PC0
static const uint8_t A1 = 15; // PC1
static const uint8_t A2 = 16; // PC2
static const uint8_t A3 = 17; // PC3
static const uint8_t A4 = 18; // PC4
static const uint8_t A5 = 19; // PC5
static const uint8_t A6 = 20; // PE2
static const uint8_t A7 = 21; // PE3

// Pin Change Interrupt
#define digitalPinToPCICR(p)    (((p)<=23) ? (&PCICR) : ((uint8_t *)0))
                                // Port D         Port B          Port C     Port C
#define digitalPinToPCICRbit(p) (((p)<=7)? 2 : (((p)<=13)? 0 : (((p)<=19)? 1 : 3)))
#define digitalPinToPCMSK(p)    (((p)<=7)? (&PCMSK2) : (((p)<=13)? (&PCMSK0) : (((p)<=19)? (&PCMSK1) : (((p)<=23)? (&PCMSK3) : ((uint8_t *)0)))))
#define digitalPinToPCMSKbit(p) (((p)<=7)? (p) : (((p)<=13)? ((p)-8) : (((p)<=19)? ((p)-14) : ((p)<=21)? ((p)-17) : ((p)-22))))

#define digitalPinToInterrupt(p)  ((p) == 2 ? 0 : ((p) == 3 ? 1 : NOT_AN_INTERRUPT))

#ifdef ARDUINO_MAIN


// these arrays map port names (e.g. port B) to the
// appropriate addresses for various functions (e.g. reading
// and writing)
const uint16_t PROGMEM port_to_mode_PGM[] = {
	NOT_A_PORT,
	NOT_A_PORT,
	(uint16_t) &DDRB,
	(uint16_t) &DDRC,
	(uint16_t) &DDRD,
	(uint16_t) &DDRE,
};

const uint16_t PROGMEM port_to_output_PGM[] = {
	NOT_A_PORT,
	NOT_A_PORT,
	(uint16_t) &PORTB,
	(uint16_t) &PORTC,
	(uint16_t) &PORTD,
	(uint16_t) &PORTE,
};

const uint16_t PROGMEM port_to_input_PGM[] = {
	NOT_A_PORT,
	NOT_A_PORT,
	(uint16_t) &PINB,
	(uint16_t) &PINC,
	(uint16_t) &PIND,
	(uint16_t) &PINE,
};

const uint8_t PROGMEM digital_pin_to_port_PGM[] = {
	PD, /* 0 */
	PD,
	PD,
	PD,
	PD,
	PD,
	PD,
	PD,
	PB, /* 8 */
	PB,
	PB,
	PB,
	PB,
	PB,
	PC, /* 14 */
	PC,
	PC,
	PC,
	PC,
	PC,
	PE, /* 20 */
	PE,
	PE,
	PE,
};

const uint8_t PROGMEM digital_pin_to_bit_mask_PGM[] = {
	_BV(0), /* 0, port D */
	_BV(1),
	_BV(2),
	_BV(3),
	_BV(4),
	_BV(5),
	_BV(6),
	_BV(7),
	_BV(0), /* 8, port B */
	_BV(1),
	_BV(2),
	_BV(3),
	_BV(4),
	_BV(5),
	_BV(0), /* 14, port C */
	_BV(1),
	_BV(2),
	_BV(3),
	_BV(4),
	_BV(5),
	_BV(2), /* 20, port E, PE2 is AD6 */
	_BV(3), // PE3 is AD7
	_BV(0), // PE0
	_BV(1), // PE1
};

const uint8_t PROGMEM digital_pin_to_timer_PGM[] = {
	TIMER3A, /* 0 - port D */
	TIMER4A,
	TIMER3B,
	TIMER2B,
	NOT_ON_TIMER,
	TIMER0B,
	TIMER0A,
	NOT_ON_TIMER,
	NOT_ON_TIMER, /* 8 - port B */
	TIMER1A,
	TIMER1B,
	TIMER2A,
	NOT_ON_TIMER,
	NOT_ON_TIMER,
	NOT_ON_TIMER, /* 14 - port C */
	NOT_ON_TIMER,
	NOT_ON_TIMER,
	NOT_ON_TIMER,
	NOT_ON_TIMER,
	NOT_ON_TIMER,
	NOT_ON_TIMER, /* 20 - port E */
	NOT_ON_TIMER,
	NOT_ON_TIMER,
	NOT_ON_TIMER,
};

#endif
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

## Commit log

2018-04-18 Modified LED pin to meet the hardware.
2018-09-11 Update README.TXT
    Modified to explain only BQ ZUM Core board.
2019-01-21 Hardware files added
    [ATMega328.SchDoc, Bill of Materials-ZUM_Core(ZUM_Core_2.xls, Bluetooth.SchDoc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]
2019-01-21 BOM file updated
    [Bill of Materials-ZUM_Core(ZUM_Core_2.0).xls, Bill of Materials-ZUM_Core(ZUM_Core_2.xls]

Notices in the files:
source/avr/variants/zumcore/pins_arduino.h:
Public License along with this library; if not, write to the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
